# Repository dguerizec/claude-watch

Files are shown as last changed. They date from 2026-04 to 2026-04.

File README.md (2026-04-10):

# Claude Watch

An ESP32-S3 device that monitors your Anthropic API usage in real time on a round display.

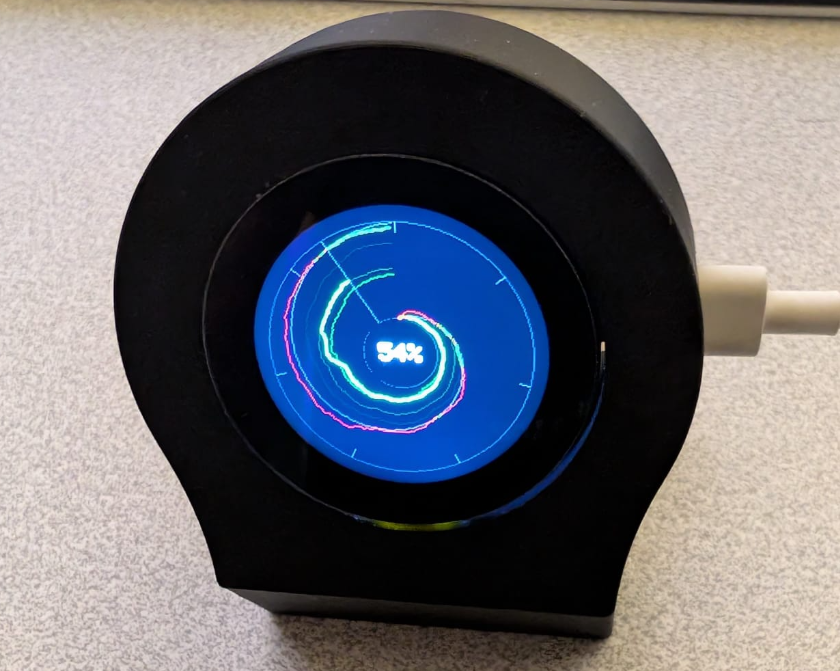
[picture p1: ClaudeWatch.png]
Claude Watch


Built with a [Seeed Studio XIAO ESP32-S3](https://wiki.seeedstudio.com/xiao_esp32s3_getting_started/) and [Round Display](https://wiki.seeedstudio.com/get_start_round_display/) (GC9A01 240x240 LCD + CHSC6X touch).

## Hardware

### BOM

| Part | Link |
|---|---|
| Seeed XIAO ESP32-S3 | [seeedstudio.com](https://www.seeedstudio.com/XIAO-ESP32S3-p-5627.html) |
| 1.28" Round Touch Display | [seeedstudio.com](https://www.seeedstudio.com/1-28-Round-Touch-Display-for-Seeed-Studio-XIAO-ESP32.html) |
| microSD card (any size) | — |

### Specs

- **MCU**: Seeed XIAO ESP32-S3 (dual-core 240MHz, 320KB SRAM, 8MB flash)
- **Display**: 1.28" round GC9A01 LCD, 240x240 RGB565
- **Touch**: CHSC6X capacitive touch controller (I2C)
- **Storage**: microSD card (SPI, shared bus with LCD)

### Pin Map

| Function | GPIO |
|---|---|
| SPI SCK  | 7 |
| SPI MOSI | 9 |
| SPI MISO | 8 |
| LCD CS | 2 |
| LCD DC | 4 |
| LCD BL | 43 |
| SD CS | 3 |
| I2C SDA  | 5 |
| I2C SCL  | 6 |
| Touch INT| 44 |

## Building

Requires [PlatformIO](https://platformio.org/).

```bash
make build        # compile
make flash        # upload to device
make monitor      # serial monitor
make flash-monitor  # flash + monitor
make clean        # clean build
make fullclean    # remove .pio entirely
make menuconfig   # ESP-IDF menuconfig
```

## Device Setup

### 1. WiFi Provisioning

On first boot (or after WiFi reset), the device starts a captive portal:

- The display shows a **QR code** encoding the AP credentials
- Scan the QR with your phone to connect to the device's WiFi
- The captive portal opens automatically — select your WiFi network, timezone, and fetch interval
- The device reboots and connects to your WiFi

### 2. Anthropic Login (OAuth)

Once connected to WiFi, the device needs authorization to access your Anthropic usage data:

- **Swipe down** on the display to show the settings QR code
- Scan the QR or open `http://<device-ip>` in a browser
- Click **"Login with Anthropic"** — authenticate in your browser
- Copy the authorization code and paste it in the settings page
- Click **Authorize** — the device exchanges the code for its own OAuth tokens

The device gets its own refresh token via PKCE — your Claude Code credentials are not affected.

### 3. Settings Page

Accessible at `http://<device-ip>` when connected to the same WiFi:

- **WiFi SSID/Password**: change WiFi network
- **Timezone**: select your timezone
- **Fetch Interval**: how often to poll the API (1–30 min)
- **OAuth Login**: authorize the device with your Anthropic account
- **Reset WiFi & Reboot**: erase WiFi credentials and restart provisioning

## Display Views

**Swipe left/right** to navigate between views. Screens can be enabled/disabled and reordered via the settings web page.

### Values View

Shows current API usage percentages and reset times for both 5-hour and 7-day billing windows.

### Polar Graph Views (7-day and 5-hour)

Radar-style polar graphs mapping a billing period onto a full circle:

- **North (12 o'clock)** = billing period reset time
- **Center** = 0% usage, **edge** = 100%
- **Clockwise** winding, one full rotation = one billing period
- **Burn-rate spiral** (gray): ideal linear consumption from 0% to 100%
- **Green** segments: under the burn rate, **red**: over
- **5 rotations** of history with progressive dimming (newest = brightest)
- **Tap** to cycle center display: usage % → burn rate ratio → delta (green/red)

### Clock View

Shows date and time in ISO 24H format, updated every second.

### Gestures

| Gesture | Action |
|---|---|
| **Swipe left** | Next screen |
| **Swipe right** | Previous screen |
| **Swipe down** | Show settings page QR code |
| **Tap** (on settings QR) | Dismiss QR, return to previous screen |
| **Long press 3s** (on settings QR) | Reset WiFi and reboot |
| **Tap** (on graph views) | Cycle center display mode |

## Architecture

### Components

| Component | Purpose |
|---|---|
| `gc9a01` | GC9A01 LCD driver (SPI) |
| `chsc6x` | CHSC6X touch driver (I2C) |
| `display_text` | 5x7 bitmap font renderer |
| `qr_display` | QR code generator and display |
| `wifi_manager` | WiFi provisioning, captive portal, settings web server, OAuth PKCE |
| `api_client` | Anthropic API client with automatic token refresh |
| `usage_store` | SD card CSV storage with lazy mount/unmount |
| `polar_graph` | Strip-based polar graph renderer with double-buffered DMA |
| `dns_server` | Captive portal DNS redirect |

### SPI Bus Sharing

The LCD and SD card share the same SPI bus (SPI2). To avoid ISR race conditions ([espressif/esp-idf#17860](https://github.com/espressif/esp-idf/issues/17860)):

- A single **display task** owns the SPI bus — all LCD and SD operations go through a FreeRTOS queue
- SD card uses **lazy mount/unmount** (mount, write, unmount) to avoid keeping two SPI devices active simultaneously
- The polar graph uses **double-buffered strip rendering** (two 19KB DMA buffers alternated) to prevent async DMA from reading freed memory

### Data Flow

```
Auto-fetch timer (10min)
       |
  fetch_usage_task ──HTTP──> Anthropic API
       |
  DISP_MSG_USAGE ──queue──> display_task
                               |
                    ┌──────────┼──────────┐
                    v          v          v
              SD card write  LCD draw   Graph render
              (mount/write/  (values    (read SD +
               unmount)       screen)    polar plot)
```

## Desk Stand (3D Print)

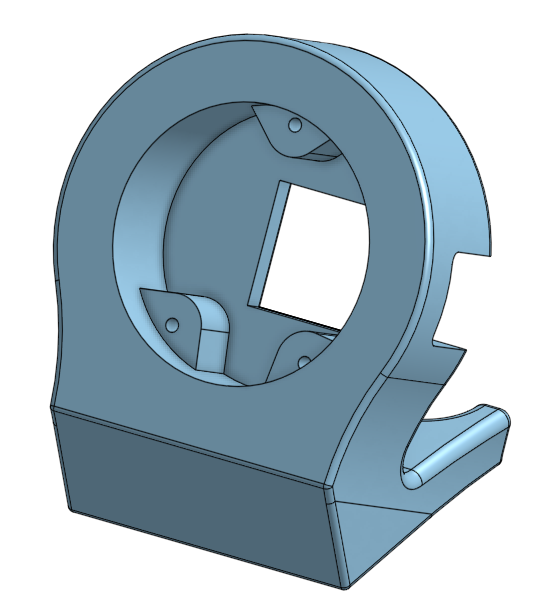
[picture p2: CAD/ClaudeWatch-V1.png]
Desk Stand


A 3D-printable desk stand is available as a [STEP file](CAD/ClaudeWatch-V1.step).

## License

MIT

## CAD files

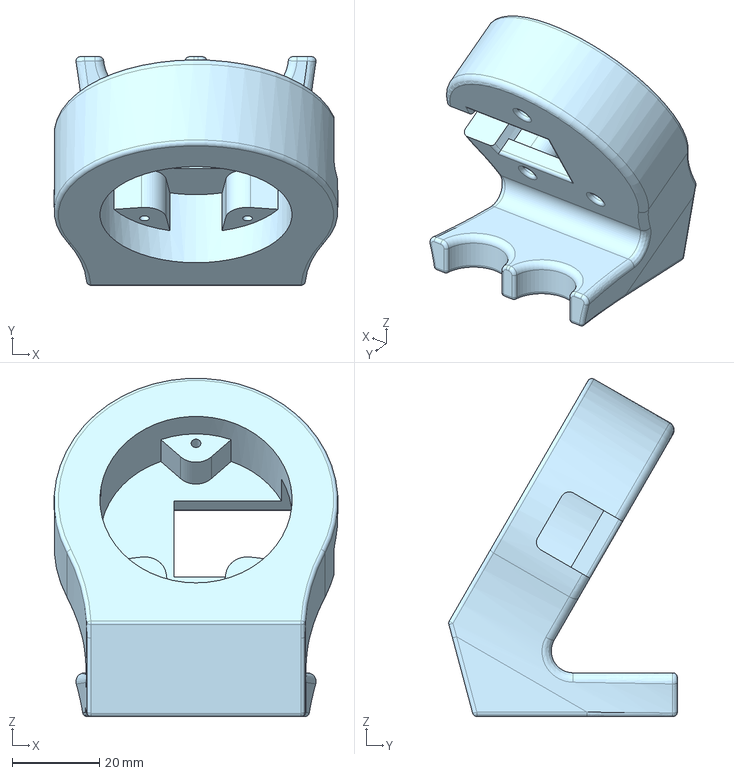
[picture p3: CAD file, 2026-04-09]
CAD/ClaudeWatch-V1.step
64.9 x 52.3 x 77.4 mm

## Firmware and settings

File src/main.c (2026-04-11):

#include <stdio.h>
#include <string.h>
#include <stdlib.h>
#include <math.h>
#include <time.h>
#include <sys/time.h>
#include "freertos/FreeRTOS.h"
#include "freertos/task.h"
#include "freertos/timers.h"
#include "freertos/queue.h"
#include "esp_log.h"
#include "esp_sntp.h"
#include "driver/spi_master.h"
#include "driver/gpio.h"
#include "esp_lcd_panel_io.h"
#include "esp_lcd_panel_ops.h"
#include "esp_lcd_gc9a01.h"
#include "driver/i2c_master.h"
#include "chsc6x.h"
#include "display_text.h"
#include "qr_display.h"
#include "wifi_manager.h"
#include "api_client.h"
#include "usage_store.h"
#include "polar_graph.h"

static const char *TAG = "claude-monitor";

/* Seeed XIAO ESP32-S3 Round Display pinout
 * SPI bus shared between LCD and SD card
 * I2C bus shared between CHSC6X touch (0x2E) and PCF8563 RTC (0x51)
 */
#define PIN_SPI_SCLK    GPIO_NUM_7   /* D8 — shared LCD + SD */
#define PIN_SPI_MOSI    GPIO_NUM_9   /* D10 — shared LCD + SD */
#define PIN_SPI_MISO    GPIO_NUM_8   /* D9 — SD card read */
#define PIN_LCD_CS      GPIO_NUM_2   /* D1 */
#define PIN_LCD_DC      GPIO_NUM_4   /* D3 */
#define PIN_LCD_BL      GPIO_NUM_43  /* D6 */
#define PIN_SD_CS       GPIO_NUM_3   /* D2 */

#define PIN_TOUCH_SDA   GPIO_NUM_5   /* D4 */
#define PIN_TOUCH_SCL   GPIO_NUM_6   /* D5 */
#define PIN_TOUCH_INT   GPIO_NUM_44  /* D7 — active LOW when touched */

#define LCD_H_RES       240
#define LCD_V_RES       240
#define LCD_PIXEL_CLK   (40 * 1000 * 1000)

/* Colors (RGB565) */
#define COLOR_BLACK   0x0000
#define COLOR_WHITE   0xFFFF
#define COLOR_RED     0xF800
#define COLOR_GREEN   0x07E0
#define COLOR_DKBLUE  0x000A
#define COLOR_DKGREEN 0x0320
#define COLOR_DKRED   0x8000

/* ─── Display message queue ─────────────────────────────────────────────
 * All LCD and SD card operations go through display_task via this queue.
 * This avoids concurrent SPI access from multiple FreeRTOS tasks. */

typedef enum {
    DISP_MSG_WIFI_STATE,
    DISP_MSG_LOADING,
    DISP_MSG_USAGE,
    DISP_MSG_ERROR,
    DISP_MSG_NO_TOKEN,
    DISP_MSG_TOGGLE,
    DISP_MSG_SETTINGS,
    DISP_MSG_DISMISS,
    DISP_MSG_TAP,
} disp_msg_type_t;

typedef struct {
    disp_msg_type_t type;
    union {
        wifi_mgr_state_t wifi_state;
        api_usage_t usage;
        int direction;  /* +1 = next, -1 = prev (for DISP_MSG_TOGGLE) */
    };
} disp_msg_t;

static QueueHandle_t s_display_queue = NULL;
static esp_lcd_panel_handle_t s_panel = NULL;

/* ─── LCD helpers ───────────────────────────────────────────────────── */

static void lcd_backlight_init(void)
{
    gpio_config_t bl_cfg = {
        .pin_bit_mask = 1ULL << PIN_LCD_BL,
        .mode = GPIO_MODE_OUTPUT,
    };
    gpio_config(&bl_cfg);
    gpio_set_level(PIN_LCD_BL, 1);
}

static uint16_t swap16(uint16_t c) { return (c >> 8) | (c << 8); }

static void fill_screen(esp_lcd_panel_handle_t panel, uint16_t color)
{
    uint16_t *line_buf = heap_caps_malloc(LCD_H_RES * sizeof(uint16_t), MALLOC_CAP_DMA);
    assert(line_buf);
    uint16_t c = swap16(color);
    for (int i = 0; i < LCD_H_RES; i++) {
        line_buf[i] = c;
    }
    for (int y = 0; y < LCD_V_RES; y++) {
        esp_lcd_panel_draw_bitmap(panel, 0, y, LCD_H_RES, y + 1, line_buf);
    }
    free(line_buf);
}

/* ─── SNTP time sync ────────────────────────────────────────────────── */

static void init_time_sync(void)
{
    static bool initialized = false;
    if (initialized) return;
    initialized = true;

    wifi_mgr_credentials_t creds;
    wifi_mgr_get_credentials(&creds);
    const char *tz = strlen(creds.timezone) > 0 ? creds.timezone : "CET-1CEST,M3.5.0,M10.5.0/3";
    setenv("TZ", tz, 1);
    tzset();
    ESP_LOGI(TAG, "Timezone: %s", tz);

    esp_sntp_setoperatingmode(SNTP_OPMODE_POLL);
    esp_sntp_setservername(0, "pool.ntp.org");
    esp_sntp_set_sync_interval(15 * 60 * 1000);
    esp_sntp_init();
    ESP_LOGI(TAG, "SNTP initialized — resync every 15 min");
}

/* ─── Fetch task (HTTP only — no LCD access) ────────────────────────── */

static TaskHandle_t s_fetch_task = NULL;

static void fetch_usage_task(void *arg)
{
    wifi_mgr_credentials_t creds;
    wifi_mgr_get_credentials(&creds);

    if (strlen(creds.refresh_token) == 0) {
        disp_msg_t msg = { .type = DISP_MSG_NO_TOKEN };
        xQueueSend(s_display_queue, &msg, portMAX_DELAY);
        s_fetch_task = NULL;
        vTaskDelete(NULL);
        return;
    }

    /* Signal loading */
    disp_msg_t msg = { .type = DISP_MSG_LOADING };
    xQueueSend(s_display_queue, &msg, portMAX_DELAY);

    /* HTTP request (needs 16KB stack for TLS) */
    api_usage_t usage;
    esp_err_t err = api_client_get_usage(creds.access_token, creds.refresh_token, &usage);

    if (err == ESP_OK && usage.valid) {
        msg.type = DISP_MSG_USAGE;
    } else {
        msg.type = DISP_MSG_ERROR;
    }
    msg.usage = usage;
    xQueueSend(s_display_queue, &msg, portMAX_DELAY);

    s_fetch_task = NULL;
    vTaskDelete(NULL);
}

static void fetch_and_display_usage(void)
{
    if (s_fetch_task != NULL) return;
    xTaskCreate(fetch_usage_task, "fetch_usage", 16384, NULL, 5, &s_fetch_task);
}

/* ─── Auto-fetch timer ──────────────────────────────────────────────── */

static TimerHandle_t s_auto_fetch_timer = NULL;
static int s_fetch_period_s = 600;

static void schedule_next_fetch(void);

static void auto_fetch_timer_cb(TimerHandle_t timer)
{
    (void)timer;
    ESP_LOGI(TAG, "Auto-fetch timer fired");
    fetch_and_display_usage();
    schedule_next_fetch();
}

static void schedule_next_fetch(void)
{
    time_t now = time(NULL);
    /* Align to clock: next_fetch = next multiple of period */
    time_t next = now - (now % s_fetch_period_s) + s_fetch_period_s;
    int delay_s = (int)(next - now);
    if (delay_s < 5) delay_s += s_fetch_period_s;  /* safety margin */

    if (!s_auto_fetch_timer) {
        s_auto_fetch_timer = xTimerCreate("auto_fetch",
            pdMS_TO_TICKS(delay_s * 1000),
            pdFALSE, NULL, auto_fetch_timer_cb);  /* one-shot, re-armed in cb */
    } else {
        xTimerChangePeriod(s_auto_fetch_timer, pdMS_TO_TICKS(delay_s * 1000), 0);
    }
    xTimerStart(s_auto_fetch_timer, 0);
    ESP_LOGI(TAG, "Next fetch in %ds (aligned to %d-min grid)", delay_s, s_fetch_period_s / 60);
}

static void start_auto_fetch(void)
{
    if (s_auto_fetch_timer != NULL) return;

    wifi_mgr_credentials_t creds;
    wifi_mgr_get_credentials(&creds);
    int interval_min = atoi(creds.fetch_interval);
    if (interval_min <= 0) interval_min = 10;
    s_fetch_period_s = interval_min * 60;

    time_t now = time(NULL);
    bool time_valid = (now > 1700000000);  /* SNTP synced? */

    if (!time_valid) {
        /* Time not synced yet — fetch immediately, align later */
        fetch_and_display_usage();
        s_auto_fetch_timer = xTimerCreate("auto_fetch",
            pdMS_TO_TICKS(s_fetch_period_s * 1000),
            pdFALSE, NULL, auto_fetch_timer_cb);
        xTimerStart(s_auto_fetch_timer, 0);
        ESP_LOGI(TAG, "Auto-fetch started (time not synced, immediate + %dmin)", interval_min);
    } else {
        /* Time valid — align to grid, skip if recent data exists */
        schedule_next_fetch();
        ESP_LOGI(TAG, "Auto-fetch started: every %d min (aligned)", interval_min);
    }
}

/* ─── Display screens (called only from display_task) ───────────────── */

static void draw_provisioning_screen(void)
{
    char qr_text[80];
    snprintf(qr_text, sizeof(qr_text), "WIFI:T:nopass;S:%s;;", wifi_mgr_get_ap_ssid());
    fill_screen(s_panel, COLOR_DKBLUE);
    display_text_draw_string_centered(s_panel, 8, "Setup WiFi", COLOR_WHITE, COLOR_DKBLUE, 2);
    qr_display_show(s_panel, qr_text, COLOR_BLACK, COLOR_WHITE);
    display_text_draw_string_centered(s_panel, 220, wifi_mgr_get_ap_ssid(), COLOR_WHITE, COLOR_DKBLUE, 1);
}

static void draw_connecting_screen(void)
{
    fill_screen(s_panel, COLOR_BLACK);
    display_text_draw_string_centered(s_panel, 108, "Connecting...", COLOR_WHITE, COLOR_BLACK, 2);
}

static void draw_connected_screen(void)
{
    char url[40];
    snprintf(url, sizeof(url), "http://%s", wifi_mgr_get_sta_ip());
    fill_screen(s_panel, COLOR_DKGREEN);
    display_text_draw_string_centered(s_panel, 8, "Connected!", COLOR_WHITE, COLOR_DKGREEN, 2);
    qr_display_show(s_panel, url, COLOR_BLACK, COLOR_WHITE);
    display_text_draw_string_centered(s_panel, 220, wifi_mgr_get_sta_ip(), COLOR_WHITE, COLOR_DKGREEN, 1);
}

static void draw_failed_screen(void)
{
    fill_screen(s_panel, COLOR_DKRED);
    display_text_draw_string_centered(s_panel, 100, "WiFi Failed", COLOR_WHITE, COLOR_DKRED, 2);
    display_text_draw_string_centered(s_panel, 130, "Hold to reset", COLOR_WHITE, COLOR_DKRED, 2);
}

static void draw_loading_screen(void)
{
    fill_screen(s_panel, COLOR_BLACK);
    display_text_draw_string_centered(s_panel, 108, "Loading...", COLOR_WHITE, COLOR_BLACK, 2);
}

static uint16_t usage_color(float utilization, time_t reset_epoch, int period_secs)
{
    if (reset_epoch == 0) return COLOR_GREEN;
    time_t now = time(NULL);
    time_t period_start = reset_epoch - period_secs;
    float elapsed_frac = (float)(now - period_start) / period_secs;
    if (elapsed_frac < 0) elapsed_frac = 0;
    if (elapsed_frac > 1) elapsed_frac = 1;
    float max_burn = elapsed_frac * 100.0f;
    return (utilization > max_burn) ? COLOR_RED : COLOR_GREEN;
}

static void draw_usage_screen(api_usage_t *usage)
{
    fill_screen(s_panel, COLOR_BLACK);
    display_text_draw_string_centered(s_panel, 30, "Claude Usage", COLOR_WHITE, COLOR_BLACK, 2);

    char line[48];
    uint16_t c5h = usage_color(usage->five_hour.utilization, usage->five_hour.resets_at_epoch, 5 * 3600);
    snprintf(line, sizeof(line), "5h: %.0f%%", usage->five_hour.utilization);
    display_text_draw_string_centered(s_panel, 75, line, c5h, COLOR_BLACK, 3);
    snprintf(line, sizeof(line), "reset %s", usage->five_hour.resets_at);
    display_text_draw_string_centered(s_panel, 100, line, COLOR_WHITE, COLOR_BLACK, 1);

    uint16_t c7d = usage_color(usage->seven_day.utilization, usage->seven_day.resets_at_epoch, 7 * 24 * 3600);
    snprintf(line, sizeof(line), "7d: %.0f%%", usage->seven_day.utilization);
    display_text_draw_string_centered(s_panel, 135, line, c7d, COLOR_BLACK, 3);
    snprintf(line, sizeof(line), "reset %s", usage->seven_day.resets_at);
    display_text_draw_string_centered(s_panel, 160, line, COLOR_WHITE, COLOR_BLACK, 1);
}

static void draw_error_screen(const char *error)
{
    fill_screen(s_panel, COLOR_BLACK);
    display_text_draw_string_centered(s_panel, 80, "Error", COLOR_RED, COLOR_BLACK, 2);
    display_text_draw_string_centered(s_panel, 110, error, COLOR_WHITE, COLOR_BLACK, 1);
    display_text_draw_string_centered(s_panel, 140, "tap to retry", COLOR_WHITE, COLOR_BLACK, 1);
}

static void draw_no_token_screen(void)
{
    fill_screen(s_panel, COLOR_BLACK);
    display_text_draw_string_centered(s_panel, 60, "No Token", COLOR_RED, COLOR_BLACK, 2);
    display_text_draw_string_centered(s_panel, 100, "Set credentials at:", COLOR_WHITE, COLOR_BLACK, 1);
    char url[40];
    snprintf(url, sizeof(url), "http://%s", wifi_mgr_get_sta_ip());
    display_text_draw_string_centered(s_panel, 120, url, COLOR_GREEN, COLOR_BLACK, 1);
    qr_display_show(s_panel, url, COLOR_WHITE, COLOR_BLACK);
}

/* ─── Graph screen ──────────────────────────────────────────────────── */

typedef enum { CENTER_USAGE, CENTER_BURN_RATE, CENTER_DELTA, CENTER_COUNT } center_mode_t;
static center_mode_t s_center_mode = CENTER_USAGE;

static void draw_graph_center(float current_pct, int period_secs, time_t reset_epoch);

/* Remember active graph params for center redraw on tap */
static float s_graph_pct = 0;
static int s_graph_period = 0;
static time_t s_graph_reset = 0;

#define MAX_GRAPH_POINTS 4096

static void draw_polar_screen(api_usage_t *usage, int period_secs, int num_rotations,
                               int num_ticks, time_t reset_epoch, float current_pct,
                               usage_column_t col, float recovery_angle)
{
    time_t now = time(NULL);
    /* If no fetch yet, use now as reset reference — graph still shows SD history */
    if (reset_epoch == 0) reset_epoch = now;
    time_t data_start = now - num_rotations * (time_t)period_secs;

    usage_data_point_t *points = malloc(MAX_GRAPH_POINTS * sizeof(usage_data_point_t));
    if (!points) {
        ESP_LOGE(TAG, "Failed to alloc graph data");
        return;
    }

    /* Two-pass read: old data downsampled, recent data full resolution */
    time_t recent_start = now - period_secs;
    int old_budget = MAX_GRAPH_POINTS / 4;
    int n_old = usage_store_read(data_start, recent_start - 1, points, old_budget, 8, col);
    int n_recent = usage_store_read(recent_start, now, points + n_old,
                                    MAX_GRAPH_POINTS - n_old, 1, col);
    int n = n_old + n_recent;
    ESP_LOGI(TAG, "Graph: %d old + %d recent = %d points (%s)",
             n_old, n_recent, n, col == USAGE_COL_FIVE_HOUR ? "5h" : "7d");

    polar_graph_draw(s_panel, points, n, period_secs, num_rotations, num_ticks, reset_epoch, now, recovery_angle);
    free(points);

    s_graph_pct = current_pct;
    s_graph_period = period_secs;
    s_graph_reset = reset_epoch;
    draw_graph_center(current_pct, period_secs, reset_epoch);
}
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
void app_main(void)
{
    ESP_LOGI(TAG, "Claude Monitor starting...");

    /* Backlight ON */
    lcd_backlight_init();

    /* SPI bus (shared LCD + SD card) */
    spi_bus_config_t bus_cfg = {
        .sclk_io_num = PIN_SPI_SCLK,
        .mosi_io_num = PIN_SPI_MOSI,
        .miso_io_num = PIN_SPI_MISO,
        .quadwp_io_num = -1,
        .quadhd_io_num = -1,
        .max_transfer_sz = LCD_H_RES * 80 * sizeof(uint16_t),
    };
    ESP_ERROR_CHECK(spi_bus_initialize(SPI2_HOST, &bus_cfg, SPI_DMA_CH_AUTO));

    /* SD card storage config (lazy mount — actual mount in display_task) */
    usage_store_init(SPI2_HOST, PIN_SD_CS);

    /* LCD panel IO (SPI) */
    esp_lcd_panel_io_handle_t io_handle = NULL;
    esp_lcd_panel_io_spi_config_t io_config = {
        .dc_gpio_num = PIN_LCD_DC,
        .cs_gpio_num = PIN_LCD_CS,
        .pclk_hz = LCD_PIXEL_CLK,
        .lcd_cmd_bits = 8,
        .lcd_param_bits = 8,
        .spi_mode = 0,
        .trans_queue_depth = 10,
    };
    ESP_ERROR_CHECK(esp_lcd_new_panel_io_spi(SPI2_HOST, &io_config, &io_handle));

    /* GC9A01 panel driver */
    esp_lcd_panel_dev_config_t panel_config = {
        .reset_gpio_num = -1,
        .rgb_ele_order = LCD_RGB_ELEMENT_ORDER_BGR,
        .bits_per_pixel = 16,
    };
    ESP_ERROR_CHECK(esp_lcd_new_panel_gc9a01(io_handle, &panel_config, &s_panel));

    ESP_ERROR_CHECK(esp_lcd_panel_reset(s_panel));
    ESP_ERROR_CHECK(esp_lcd_panel_init(s_panel));
    ESP_ERROR_CHECK(esp_lcd_panel_invert_color(s_panel, true));
    ESP_ERROR_CHECK(esp_lcd_panel_mirror(s_panel, true, false));
    ESP_ERROR_CHECK(esp_lcd_panel_disp_on_off(s_panel, true));

    ESP_LOGI(TAG, "Display initialized — 240x240 GC9A01");

    /* I2C bus */
    i2c_master_bus_config_t i2c_bus_cfg = {
        .clk_source = I2C_CLK_SRC_DEFAULT,
        .i2c_port = I2C_NUM_0,
        .sda_io_num = PIN_TOUCH_SDA,
        .scl_io_num = PIN_TOUCH_SCL,
        .glitch_ignore_cnt = 7,
        .flags.enable_internal_pullup = true,
    };
    i2c_master_bus_handle_t i2c_bus = NULL;
    ESP_ERROR_CHECK(i2c_new_master_bus(&i2c_bus_cfg, &i2c_bus));

    /* CHSC6X touch controller */
    chsc6x_config_t touch_cfg = {
        .i2c_bus = i2c_bus,
        .int_gpio_num = PIN_TOUCH_INT,
    };
    chsc6x_handle_t touch = NULL;
    bool touch_ok = (chsc6x_init(&touch_cfg, &touch) == ESP_OK);

    if (touch_ok) {
        ESP_LOGI(TAG, "Touch ready");
    } else {
        ESP_LOGW(TAG, "Touch init failed — running without touch");
    }

    /* Boot splash — single-threaded here, direct LCD access is safe */
    fill_screen(s_panel, COLOR_BLACK);
    display_text_draw_string_centered(s_panel, 100, "Claude Monitor", COLOR_WHITE, COLOR_BLACK, 2);
    display_text_draw_string_centered(s_panel, 120, "Starting...", COLOR_GREEN, COLOR_BLACK, 2);

    /* Check for WiFi reset gesture (still single-threaded) */
    esp_log_level_set("i2c.master", ESP_LOG_NONE);
    if (touch_ok && check_reset_gesture(touch)) {
        fill_screen(s_panel, COLOR_BLACK);
        display_text_draw_string_centered(s_panel, 108, "WiFi Reset!", COLOR_RED, COLOR_BLACK, 2);
        wifi_mgr_init(wifi_state_cb, NULL);
        wifi_mgr_erase_credentials();
        vTaskDelay(pdMS_TO_TICKS(1000));
    } else {
        wifi_mgr_init(wifi_state_cb, NULL);
    }

    /* Load display config and last usage values from NVS */
    load_display_config();
    {
        float fh, sd;
        time_t fh_epoch, sd_epoch;
        if (wifi_mgr_load_last_usage(&fh, &fh_epoch, &sd, &sd_epoch)) {
            s_last_usage.five_hour.utilization = fh;
            s_last_usage.five_hour.resets_at_epoch = fh_epoch;
            s_last_usage.seven_day.utilization = sd;
            s_last_usage.seven_day.resets_at_epoch = sd_epoch;
            /* Format display strings from epochs */
            static const char *months[] = {"Jan","Feb","Mar","Apr","May","Jun",
                                           "Jul","Aug","Sep","Oct","Nov","Dec"};
            struct tm local;
            localtime_r(&fh_epoch, &local);
            snprintf(s_last_usage.five_hour.resets_at, sizeof(s_last_usage.five_hour.resets_at),
                     "%s %d %02d:%02d", months[local.tm_mon], local.tm_mday, local.tm_hour, local.tm_min);
            localtime_r(&sd_epoch, &local);
            snprintf(s_last_usage.seven_day.resets_at, sizeof(s_last_usage.seven_day.resets_at),
                     "%s %d %02d:%02d", months[local.tm_mon], local.tm_mday, local.tm_hour, local.tm_min);
            s_last_usage.valid = true;
            s_has_usage = true;
            ESP_LOGI(TAG, "Restored: 5h=%.0f%% 7d=%.0f%%", fh, sd);
        }
    }

    /* Create display queue + task BEFORE starting WiFi.
     * From this point on, only display_task touches the LCD/SD. */
    s_display_queue = xQueueCreate(4, sizeof(disp_msg_t));
    xTaskCreate(display_task, "display", 12288, NULL, 5, NULL);

    /* If we have cached data, draw the initial view immediately
     * to replace the boot splash without waiting for WiFi */
    if (s_has_usage) {
        disp_msg_t imsg = { .type = DISP_MSG_USAGE, .usage = s_last_usage };
        xQueueSend(s_display_queue, &imsg, pdMS_TO_TICKS(100));
    }

    /* Start WiFi — callbacks will now go through the queue */
    wifi_mgr_start();

    /* Main loop — gesture detection, no direct LCD access.
     * Swipe left/right = next/prev screen, tap = WiFi button action. */
    bool touching = false;
    uint16_t t_sx = 0, t_sy = 0, t_lx = 0, t_ly = 0;
    int t_frames = 0;

    #define SWIPE_MIN    40   /* min pixels for a swipe */
    #define TAP_MAX      15   /* max pixels for a tap */
    #define LONG_PRESS   30   /* frames (× 100ms = 3s) */

    while (1) {
        if (touch_ok) {
            chsc6x_touch_data_t td;
            if (chsc6x_read(touch, &td) == ESP_OK) {
                if (td.touched) {
                    if (!touching) {
                        t_sx = td.x; t_sy = td.y;
                        t_frames = 0;
                        touching = true;
                    }
                    t_lx = td.x; t_ly = td.y;
                    t_frames++;

                    /* Long press on settings overlay → WiFi reset */
                    if (t_frames == LONG_PRESS
                        && s_settings_overlay
                        && abs((int)t_lx - (int)t_sx) < TAP_MAX
                        && abs((int)t_ly - (int)t_sy) < TAP_MAX) {
                        ESP_LOGI(TAG, "Long press on settings — WiFi reset");
                        wifi_mgr_erase_credentials();
                        vTaskDelay(pdMS_TO_TICKS(500));
                        esp_restart();
                    }
                } else if (touching) {
                    touching = false;
                    int dx = (int)t_lx - (int)t_sx;
                    int dy = (int)t_ly - (int)t_sy;
                    wifi_mgr_state_t st = wifi_mgr_get_state();
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

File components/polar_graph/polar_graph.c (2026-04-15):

#include "polar_graph.h"
#include "esp_log.h"
#include "esp_heap_caps.h"
#include <math.h>
#include <string.h>
#include <stdlib.h>

static const char *TAG = "polar_graph";

#define CX       120
#define CY       120
#define MIN_R    30       /* 0% radius — leaves room for text at center */
#define MAX_R    108
#define W        240
#define H        240
#define STRIP_H  40       /* rows per strip — 240*40*2 = 19,200 bytes */
#define SPIRAL_N 180      /* points for burn-rate spiral (every 2°) */

static inline uint16_t sw(uint16_t c) { return (c >> 8) | (c << 8); }

/* ── Strip-local drawing primitives ──────────────────────────────────── */

static inline void spx(uint16_t *strip, int sy, int sh, int x, int y, uint16_t c)
{
    int ly = y - sy;
    if ((unsigned)x < W && (unsigned)ly < (unsigned)sh)
        strip[ly * W + x] = c;
}

static void sline(uint16_t *strip, int sy, int sh,
                  int x0, int y0, int x1, int y1, uint16_t c)
{
    int dx = abs(x1 - x0), step_x = x0 < x1 ? 1 : -1;
    int dy = -abs(y1 - y0), step_y = y0 < y1 ? 1 : -1;
    int err = dx + dy;
    for (;;) {
        spx(strip, sy, sh, x0, y0, c);
        if (x0 == x1 && y0 == y1) break;
        int e2 = 2 * err;
        if (e2 >= dy) { err += dy; x0 += step_x; }
        if (e2 <= dx) { err += dx; y0 += step_y; }
    }
}

/* Midpoint circle — 8-way symmetric, no gaps */
static void draw_circle(uint16_t *strip, int sy, int sh, int r, uint16_t c)
{
    int x = r, y = 0, d = 1 - r;
    while (x >= y) {
        spx(strip, sy, sh, CX+x, CY+y, c); spx(strip, sy, sh, CX-x, CY+y, c);
        spx(strip, sy, sh, CX+x, CY-y, c); spx(strip, sy, sh, CX-x, CY-y, c);
        spx(strip, sy, sh, CX+y, CY+x, c); spx(strip, sy, sh, CX-y, CY+x, c);
        spx(strip, sy, sh, CX+y, CY-x, c); spx(strip, sy, sh, CX-y, CY-x, c);
        y++;
        if (d <= 0) d += 2 * y + 1;
        else { x--; d += 2 * (y - x) + 1; }
    }
}

static inline void polar_xy(float angle, float r, int *x, int *y)
{
    *x = CX + (int)(r * sinf(angle));
    *y = CY - (int)(r * cosf(angle));
}

/* Draw an arc between two polar points, interpolating in polar space.
 * For small angular distances, this degenerates to a single sline. */
static void polar_arc(uint16_t *strip, int sy, int sh,
                      float a0, float r0, float a1, float r1, uint16_t c)
{
    float da = a1 - a0;
    /* Shortest path around the circle */
    if (da > M_PI) da -= 2.0f * M_PI;
    if (da < -M_PI) da += 2.0f * M_PI;

    /* ~3 pixels per sub-segment at the outer radius */
    int steps = (int)(fabsf(da) * MAX_R / 3.0f) + 1;
    if (steps > 120) steps = 120;

    int px = CX + (int)(r0 * sinf(a0));
    int py = CY - (int)(r0 * cosf(a0));
    for (int s = 1; s <= steps; s++) {
        float t = (float)s / steps;
        float a = a0 + da * t;
        float r = r0 + (r1 - r0) * t;
        int nx = CX + (int)(r * sinf(a));
        int ny = CY - (int)(r * cosf(a));
        sline(strip, sy, sh, px, py, nx, ny, c);
        px = nx;
        py = ny;
    }
}

/* Compute burn rate (0–100) for a timestamp within its billing period */
static inline float burn_rate_at(time_t ts, time_t week_start, int psecs)
{
    float frac = (float)(ts - week_start) / psecs;
    if (frac < 0.0f) frac = 0.0f;
    if (frac > 1.0f) frac = 1.0f;
    return frac * 100.0f;
}

/* ── Color tables — progressively dimmer for older rotations ──────────── */

#define MAX_ROTATIONS 8

/* Green (under budget): bright → dim.  History shifts to cyan (+blue). */
static const uint16_t greens[MAX_ROTATIONS] = {
    0x07E0, 0x04F3, 0x02EB, 0x0165, 0x00C3, 0x0061, 0x0041, 0x0021,
};

/* Red (over budget): bright → dim.  History shifts to violet (+blue). */
static const uint16_t reds[MAX_ROTATIONS] = {
    0xF800, 0xA014, 0x600C, 0x3006, 0x1803, 0x1002, 0x0801, 0x0801,
};

/* ── Public API ──────────────────────────────────────────────────────── */

void polar_graph_draw(esp_lcd_panel_handle_t panel,
                      const usage_data_point_t *points, int num_points,
                      int period_secs, int num_rotations, int num_ticks,
                      time_t period_end, time_t now,
                      float recovery_angle)
{
    /* Pre-compute per-point: screen coords, week index, color.
     * int16_t for coords (0–239 range) to halve memory vs int. */
    if (num_rotations > MAX_ROTATIONS) num_rotations = MAX_ROTATIONS;

    int16_t *scr_x = NULL, *scr_y = NULL;
    float *pt_angle = NULL, *pt_radius = NULL;
    uint8_t *pt_week = NULL;
    uint16_t *pt_color = NULL;

    if (num_points > 0) {
        scr_x = malloc(num_points * sizeof(int16_t));
        scr_y = malloc(num_points * sizeof(int16_t));
        pt_angle = malloc(num_points * sizeof(float));
        pt_radius = malloc(num_points * sizeof(float));
        pt_week = malloc(num_points);
        pt_color = malloc(num_points * sizeof(uint16_t));
        if (!scr_x || !scr_y || !pt_angle || !pt_radius || !pt_week || !pt_color) {
            free(scr_x); free(scr_y); free(pt_angle); free(pt_radius);
            free(pt_week); free(pt_color);
            ESP_LOGE(TAG, "Failed to alloc point arrays");
            return;
        }
        for (int i = 0; i < num_points; i++) {
            /* Angular position (wraps every 7 days, north = period_end) */
            float frac = (float)(points[i].timestamp - period_end) / period_secs;
            frac = fmodf(frac, 1.0f);
            if (frac < 0.0f) frac += 1.0f;
            float angle = 2.0f * M_PI * frac;
            float r = MIN_R + (points[i].value / 100.0f) * (MAX_R - MIN_R);
            if (r < MIN_R) r = MIN_R;
            if (r > MAX_R) r = MAX_R;
            pt_angle[i] = angle;
            pt_radius[i] = r;
            int sx, sy;
            polar_xy(angle, r, &sx, &sy);
            scr_x[i] = sx;
            scr_y[i] = sy;

            /* Week index: 0 = current, 1 = previous, ... */
            int w_actual = (int)((float)(period_end - points[i].timestamp) / period_secs);
            if (w_actual < 0) w_actual = 0;
            int w = (w_actual >= num_rotations) ? num_rotations - 1 : w_actual;
            pt_week[i] = w;

            /* Color: green/red based on burn rate — use actual period, not clamped */
            time_t week_start = period_end - (w_actual + 1) * (time_t)period_secs;
            float br = burn_rate_at(points[i].timestamp, week_start, period_secs);
            bool over = (points[i].value >= br);
            int dim = (w_actual >= MAX_ROTATIONS) ? MAX_ROTATIONS - 1 : w_actual;
            pt_color[i] = sw(over ? reds[dim] : greens[dim]);
        }
    }

    /* Pre-compute burn-rate spiral */
    int spi_x[SPIRAL_N], spi_y[SPIRAL_N];
    for (int i = 0; i < SPIRAL_N; i++) {
        float frac = (float)i / SPIRAL_N;
        float angle = 2.0f * M_PI * frac;
        float r = MIN_R + frac * (MAX_R - MIN_R);
        polar_xy(angle, r, &spi_x[i], &spi_y[i]);
    }
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

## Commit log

2026-04-05 Initial project setup: PlatformIO + ESP-IDF for Xiao ESP32-S3
    Seeed XIAO ESP32-S3 with 1.28" round display (GC9A01).
    PlatformIO with ESP-IDF/FreeRTOS backend (no Arduino).
2026-04-06 Add GC9A01 display + CHSC6X touch drivers for round display
    Working display (240x240 GC9A01 via SPI) and touch (CHSC6X @ 0x2E
    via I2C) on Seeed XIAO ESP32-S3 round display. Byte-swap for RGB565
    endianness, 200ms touch debounce, Makefile for build/flash/monitor.
    [chsc6x.c, gc9a01.c, main.c]
2026-04-06 Add axis display with ticks, touch dot, and fix X coordinate
    Draw red X-axis and green Y-axis with ticks every 10px on black
    background. Show 5x5 white dot at touch position. Invert X
    coordinate to match physical screen orientation.
    [chsc6x.c, main.c]
2026-04-07 Add WiFi provisioning, captive portal, API usage display, and OAuth refresh
    Implement full WiFi lifecycle: SoftAP with captive portal and QR code for
    initial setup, NVS credential storage, station mode with config web page.
    Add Anthropic API client with automatic OAuth token refresh on 401.
    Display usage stats (5h/7d utilization) on the round screen on touch.
    New components:
    - display_text: bitmap font rendering (5x7) on LCD
    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
    [partitions.csv]
2026-04-07 Add SNTP time sync, timezone setting, and local time display
    Sync time via SNTP (pool.ntp.org) on WiFi connect, resync every 15 min.
    Add configurable timezone dropdown to both config and captive portal pages,
    stored in NVS. Convert API reset times from UTC to local time for display.
    Auto-generate portal_html.h from portal.html at CMake configure time.
    [main.c]
2026-04-07 Add SD card storage, display task queue, and fetch interval setting
    Refactor display to single-task architecture: all LCD and SD card
    access goes through display_task via FreeRTOS queue, fixing SPI bus
    race condition on dual-core ESP32-S3 (concurrent access from WiFi
    callback + fetch task). SD card uses lazy mount/write/unmount to avoid
    ISR conflict with LCD on shared SPI bus (espressif/esp-idf#17860).
    - Add usage_store component: CSV logging to SD card
    - Add configurable fetch interval in captive portal
    - Enable FAT long filenames and SPI_MASTER_IN_IRAM
    - Add convert_usage.py script for importing history from claude-usage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
    [main.c, usage_store.c]
2026-04-07 Add polar graph view with tap-to-toggle and historical data display
    Polar graph maps 7-day usage onto the round display: center=0%,
    edge=100%, clockwise from north, with a white "now" hand. Tap toggles
    between value view and graph view; auto-fetch continues in background.
    - Add polar_graph component: strip-based rendering with double-buffered
    DMA to avoid async SPI transfer artifacts
    - Add usage_store_read() for reading historical CSV data from SD card
    - Add resets_at_epoch to api_usage_tier_t for period calculation
    - Tap toggles view instead of triggering refetch
    [main.c, polar_graph.c, usage_store.c]
2026-04-07 Fix polar graph: show last 7 days, north=reset, double-buffer DMA
    - Read data for last 7 days before now (full circle) instead of
    billing period only (partial circle)
    - North (12 o'clock) = resets_at (billing period end)
    - Angles use fmodf to wrap correctly around the circle
    - Now-line position relative to reset timestamp
    [main.c, polar_graph.c]
2026-04-07 Add burn-rate spiral, color-coded data, and fix circle rendering
    - Burn-rate spiral: Archimedean spiral from 0% to 100% over one full
    rotation, showing the ideal linear consumption rate
    - Data color: green if under burn rate, red if over, with bright/dark
    shades for current/previous billing week
    - Break polyline at billing period boundary (no vertical artifact)
    - Now-line: dark gray, MIN_R to MAX_R only (not through center)
    - MIN_R=30px offset so 0% data doesn't overlap center text
    - Midpoint circle algorithm (8-way symmetric) replaces analytical
    per-row method that left gaps in near-horizontal arcs
    [polar_graph.c]
2026-04-07 Show 5-week history, silent background events, and preserve tokens
    - Display 5 weeks of data (oldest dimmed, newest bright) with z-order
    rendering (oldest first, newest last for correct overlap)
    - Downsample old data (stride 8) to fit 4096-point budget while
    keeping recent week at full resolution
    - Use int16_t for screen coords to halve memory usage
    - WiFi reconnects, loading, and fetch errors no longer overwrite
    the display once usage data has been shown
    - WiFi reset (hold 3s) only erases SSID/password, preserves tokens
    and settings
    - Fix timer task stack overflow (2048 → 4096)
    [main.c, polar_graph.c, usage_store.c]
2026-04-08 Add clock view, fix graph reset lines, 3-view tap cycle
    - Add clock page showing ISO date and 24H time, refreshed every second
    without full-screen redraw (no flicker)
    - Tap cycles through 3 views: usage → graph → clock
    - Break graph polyline when value decreases (= billing period reset)
    instead of tracking period indices — simpler and correct by design
    [main.c, polar_graph.c]
2026-04-08 Add WiFi button on clock page, settings QR, and web WiFi management
    - Clock page: 60px WiFi button at bottom, rendered in single DMA
    buffer to avoid heap corruption from async SPI transfers
    - Short tap on button: show settings page QR code
    - Long press (3s): erase WiFi credentials and reboot
    - Settings web page: add SSID/password fields to change WiFi,
    add "Reset WiFi & Reboot" button with /wifi-reset endpoint
    [main.c]
2026-04-08 Add OAuth PKCE login flow to settings page
    Device gets its own refresh token via OAuth — no need to steal
    Claude Code's token. Flow:
    1. Settings page shows "Login with Anthropic" link (PKCE challenge)
    2. User authenticates on claude.ai, gets authorization code
    3. User pastes code, ESP32 exchanges it for tokens via
    POST to console.anthropic.com/v1/oauth/token
    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
2026-04-08 Add BOM with product links to README
2026-04-08 Add 5-hour polar graph view with configurable ticks and periods
    - New VIEW_GRAPH_5H: polar graph for 5-hour usage (2π = 5h, 5 ticks)
    - Cycle: values → graph 7d → graph 5h → clock (4 views)
    - polar_graph_draw now accepts period_secs, num_rotations, num_ticks
    as parameters instead of hardcoded 7-day/7-tick values
    - usage_store_read accepts column selector (five_hour vs seven_day)
    - Refactor draw_polar_screen as shared helper for both graphs
2026-04-08 Expand app partition to use full 8MB flash
    Factory partition: 0x300000 (3MB) → 0x7F0000 (~8MB).
    Flash usage drops from 37.5% to 14.2%.
    [partitions.csv]
2026-04-08 Add TypeScript SPA settings page, display config, and aligned fetch
    Settings page:
    - TypeScript SPA with 3 tabs (Settings, Account, Display) built with
    esbuild, served as static HTML via REST API endpoints
    - Display tab: enable/disable screens and reorder via up/down arrows
    - Config stored in NVS, read at boot and on each tap toggle
    Boot sequence:
    - Skip "Connecting..." and "Loading..." on normal reboot (has token)
    - Draw initial view (clock/loading) directly after WiFi connects
    - QR "Connected!" only shown on first setup (no token)
    Fetch scheduling:
    - Aligned to clock grid: next_fetch = now - (now % period) + period
    - One-shot timer re-armed after each fetch for precise alignment
    - No i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
    [main.c]
2026-04-08 Add polar arc interpolation, show SD history before first fetch
    - Replace straight Bresenham lines with polar arc interpolation:
    segments interpolate in (angle, radius) space, following the circle
    instead of cutting chords. ~3px per sub-segment at outer radius.
    - Allow view toggle before first API fetch — graphs show SD card
    historical data immediately, center shows "--" until fetch arrives
    - Use now as fallback period_end when no fetch has occurred yet
    - Remove s_has_usage guard from TOGGLE handler
    [main.c, polar_graph.c]
2026-04-09 Fix clock overwriting provisioning QR and settings screens
    Clock refresh only ticks when all conditions are met:
    - Current view is clock
    - WiFi is connected
    - First usage data has been received (token is working)
    Prevents the 1-second clock timer from overwriting the WiFi
    provisioning QR code or the "Connected!" settings QR.
    [main.c]
2026-04-09 Add swipe left/right navigation between screens
    Replace tap-to-toggle with gesture detection:
    - Swipe left: next screen
    - Swipe right: previous screen
    - Tap on WiFi button (clock view): show settings QR
    - Long press (3s) on WiFi button: reset WiFi and reboot
    Touch polling reduced to 50ms for smoother gesture detection.
    Swipe threshold: 40px min, 2:1 horizontal/vertical ratio.
    Direction field added to DISP_MSG_TOGGLE for prev/next.
    [main.c]
2026-04-09 Add swipe-down for settings QR, tap/timeout to dismiss
    - Swipe down from any screen shows settings page QR code
    - Any touch or 60-second timeout dismisses the overlay and restores
    the previous screen
    - Long press (3s) resets WiFi from any screen (not just clock)
    - WiFi button on clock view no longer needed for settings access
    - Refactor view redraw as goto label to share between toggle/dismiss
    [main.c]
2026-04-09 Cache last usage values in NVS for instant display after reboot
    Store 16 bytes in NVS (2 floats + 2 time_t): utilization percentages
    and reset epochs for both 5h and 7d tiers. Display strings are
    recomputed from epochs at boot via localtime_r, not stored.
    At boot: values screen shows real data immediately, graphs are
    correctly aligned to billing period, no more "0%" until first fetch.
    [main.c]
2026-04-09 Add tap-to-cycle center display on polar graphs
    Tap on graph 7d/5h cycles between three center display modes:
    - Usage percentage (white)
    - Burn rate ratio: usage/max_burn (cyan)
    - Delta: max_burn - usage with +/- prefix (green/red)
    Center cleared with a filled black circle (radius=MIN_R) matching
    the inner graph boundary — no pixel residue between mode switches.
    Removed unused WiFi button hit-test function.
    [main.c]
2026-04-09 Add 3D printed desk stand model (STEP + screenshot)
    [ClaudeWatch-V1.step]
2026-04-10 Add device photo to README
2026-04-10 Add desk stand section to README with CAD screenshot
2026-04-10 Remove WiFi button from clock, restrict long press to settings QR
    - Remove draw_wifi_button and all BTN_* defines from clock screen
    - Long press (3s) WiFi reset only works on settings QR overlay,
    no longer from any screen
    - Settings QR accessible via swipe down from any screen
    - Update README: accurate gesture docs, remove WiFi button references,
    document tap-to-cycle on graph views
    [main.c]
2026-04-11 Add Graph 7-day view with recovery marker, rename history view
    - New VIEW_GRAPH_7D: single rotation with red triangle recovery
    marker (tr) at the edge when burn rate > 100%
    - Existing 5-rotation view renamed to VIEW_GRAPH_7D_HIST
    - Recovery angle: 2pi * usage/100 — where burn rate catches up
    if consumption stops
    - Updated SPA and display config for 5 screens
    Known issues: color bug on 7d view, clock view missing from cycle
    [main.c, polar_graph.c]
2026-04-11 Fix burn rate color and auto-migrate stale display config
    - Color bug: use actual billing period (w_actual) for burn rate
    comparison, not the clamped week index
    - Stale config auto-migration: if NVS display_cfg has fewer entries
    than VIEW_COUNT, reset to defaults with all screens enabled and
    persist to NVS so web UI stays in sync
    - Add wifi_mgr_set_display_config() for programmatic config updates
    [main.c, polar_graph.c]
2026-04-11 Fix dimming with actual week index, boot splash, and text overlap
    - Dimming: use w_actual (unclamped) for color table index, so data
    from previous periods is properly dimmed even with num_rotations=1
    - Boot: send cached usage data to display_task immediately after
    creation to replace splash without waiting for WiFi
    - Move "Hold 3s: reset" text from y=130 to y=140 to avoid overlap
    with "Starting..." at y=120
    [main.c, polar_graph.c]
2026-04-11 Show usage values in red when exceeding burn rate, remove tap hint
    [main.c]
2026-04-15 Change history graph colors: dimmed green→cyan, dimmed red→violet
